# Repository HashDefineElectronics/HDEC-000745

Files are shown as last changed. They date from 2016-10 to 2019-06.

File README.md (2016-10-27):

# HDEC-000745
Robot and image processing developement platform

## Project page
https://www.hashdefineelectronics.com/micro-robot-development-platform-hdec-000745/

## Video
3D printing micro robot chassis (time lapse)

#3 time lapse 3D printing micro robot chassis (https://youtu.be/097JlulddWc)

# 1) Initial project setup
When you first clone the project you will need to use the --recursive parameter to clone any of the git submodules used by the project.

`git clone --recursive https://github.com/HashDefineElectronics/HDEC-000745.git`

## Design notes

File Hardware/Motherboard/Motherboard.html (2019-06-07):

# BOM Rev

Date

Company

Comment 1

Comment 2

Comment 3

Comment 4

Total Parts

# 18 (Unique 12)

Ref

Qty

Value

Footprint

C_Value

Description

Manufacture

Supplier

Supplier No.

[C] -

C1 C2

2

MC0402N300J500CT

Capacitors:CAP_0402

30pF 50V 5%

30pF 50V 0402 -55C to 125C COG/NP0 5%

KEMET

Farnell

1758954

C3 C4 C5

3

C0402C104K4RACAUTO

Capacitors:CAP_0402

100nF 16V 10%

100nF 16V 0603 -55C to 125C X7R 10% Automotive

KEMET

Farnell

2070374

C6

1

C0805C106K8PACTU

Capacitors:CAP_0805

10uF 10V 10%

10uF 10V 0805 X5R 10%

KEMET

Farnell

1463362

[D] -

D1

1

KP-1608SURCK

Diodes:LED_1.6mmx0.8mm

Red

Red 0.8mm 1.6mm SMD LED

KINGBRIGHT

Farnell

2290329

[J] -

J1

1

DEBUG_ARM_SW

Connectors:SHF-105-01-L-D-TH

ARM 10-Pin Serial Wire Connector (1.27mm)

SAMTEC

Farnell

2308450

[R] -

R1

1

MCMR04X1004FTL

Resistors:RES_0402

1M 62.5mW 1%

1M 0402 1% 62.5mW

MULTICOMP

Farnell

2072521

R2

1

ERJ2RKF2003X

Resistors:RES_0402

200K 0.1W 1% 75V

200K 0402 1% 0.1W 75V

PANASONIC ELECTRONIC COMPONENTS

Farnell

2059185

R3

1

ERJ2RKF1001X

Resistors:RES_0402

1K 0.1W 1%

1K 0402 1% 0.1W

PANASONIC ELECTRONIC COMPONENTS

Farnell

2302638

R4

1

CRCW0402100KFKEDHP

Resistors:RES_0402

100K 0.125W 1% 50V

100K 0402 1% 0.125W 50V

VISHAY DRALORIC

Farnell

1738877

[T] -

T1 T2 T3 T4

4

TEST_PAD

HDE_Miscellaneous:TEST_PAD_0.5mm_Hole

0.5mm Test pad

[U] -

U1

1

S9KEAZ64ACLH

IC:LQFP_64

ARM Cortex M0+ 64KB Flash 3.3V/5V LQFP-64

Freescale

Mouser

841-S9KEAZ64ACLH

[X] -

X1

1

ABM7-12.000MHZ-D2Y-T

HDE_Crystals:ABM7

12MHZ 18PF

CRYSTAL 12MHZ 18PF - 40°C to + 60°C

ABRACON

Farnell

2101331

# BOM made with KICAD_BOM_WIZARD (https://github.com/HashDefineElectronics/KiCad_BOM_Wizard) (Generated Wed 21 Jun 2017 15:26:22 BST)

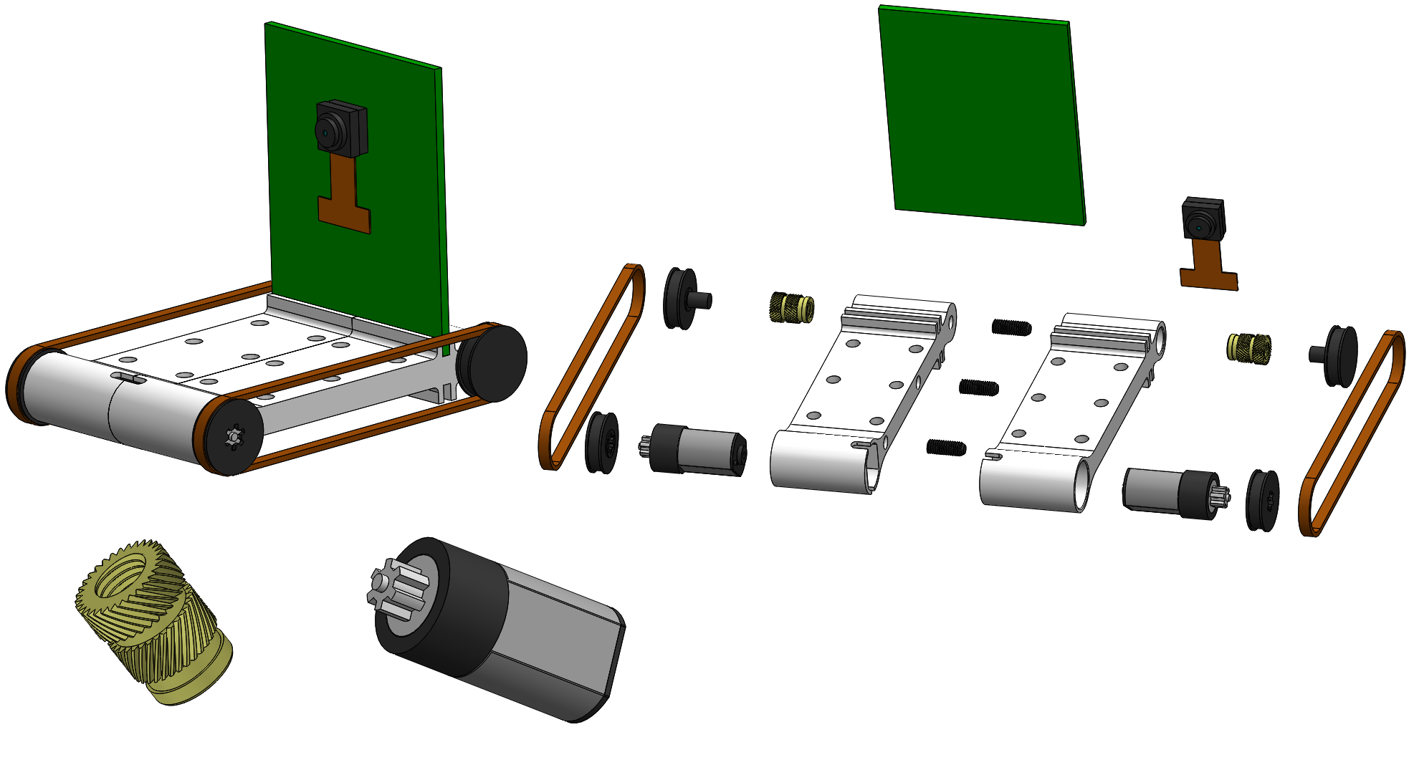
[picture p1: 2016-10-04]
Mechanical/Prototype render.png

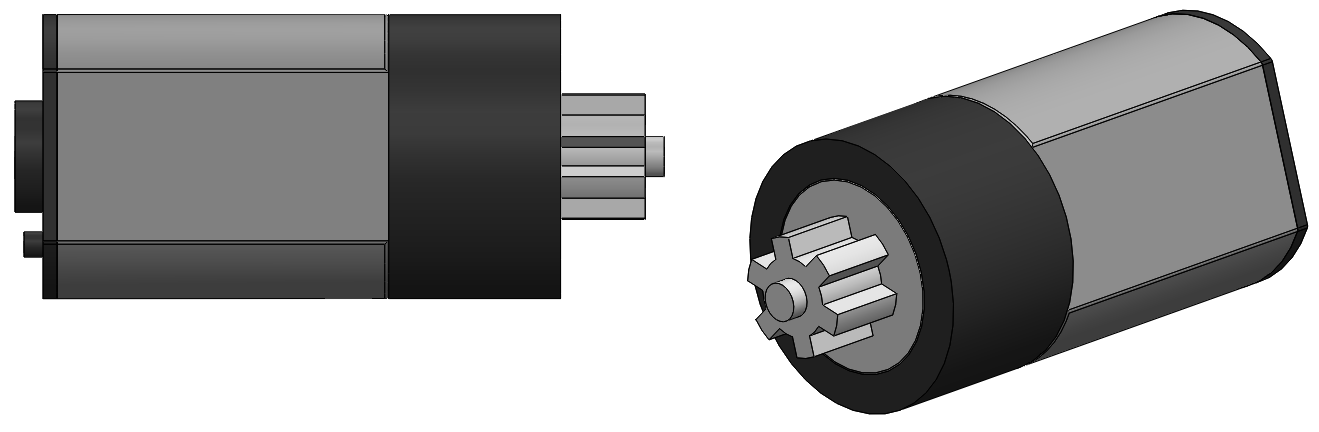
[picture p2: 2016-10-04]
Mechanical/Motor Render.png

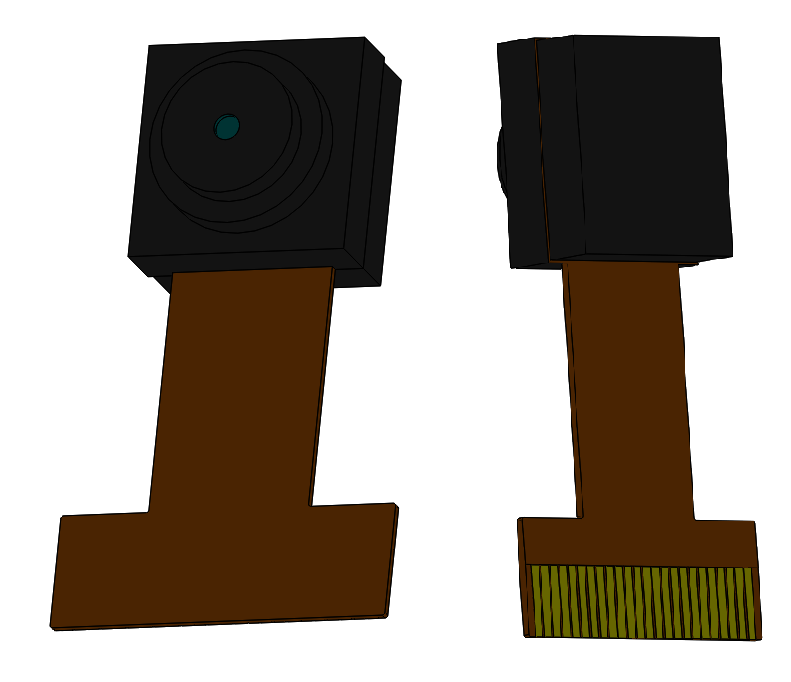
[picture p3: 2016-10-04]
Mechanical/Camera Render.png

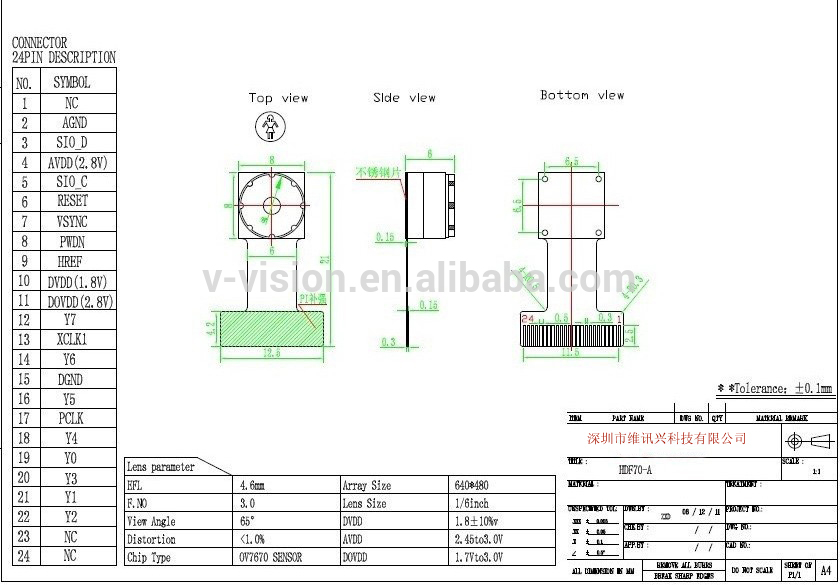
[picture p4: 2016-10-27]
Datasheet/HTB10HZ5FVXXXXb0XFXXq6xXFXXXZ.jpg

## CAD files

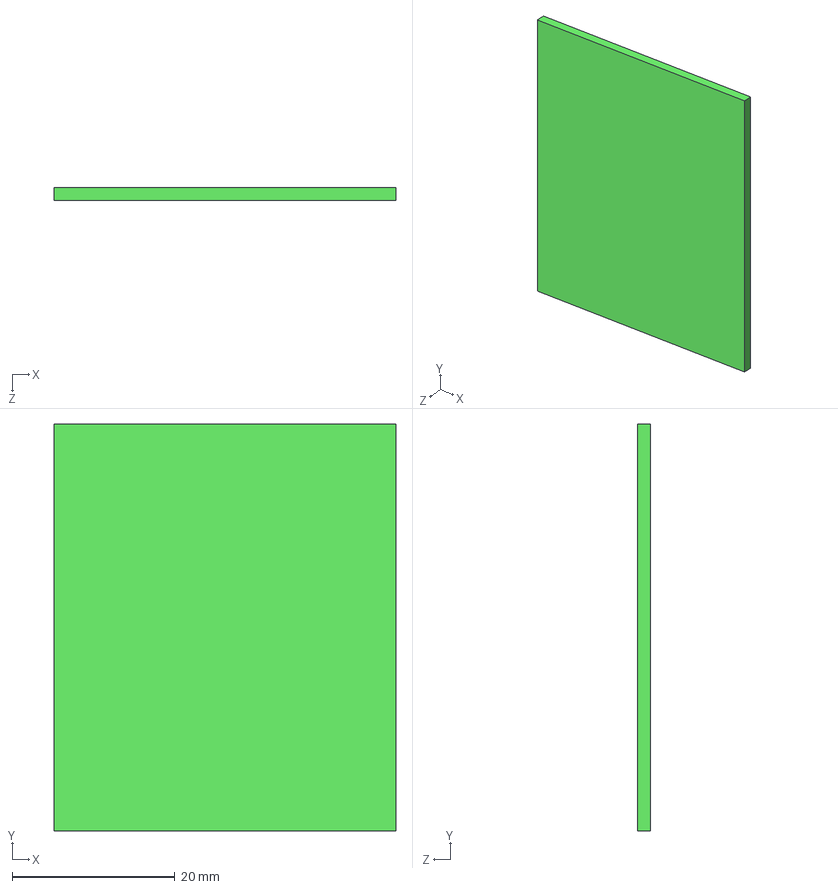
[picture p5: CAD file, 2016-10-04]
Mechanical/pcb.STEP
42.0 x 50.0 x 1.60 mm

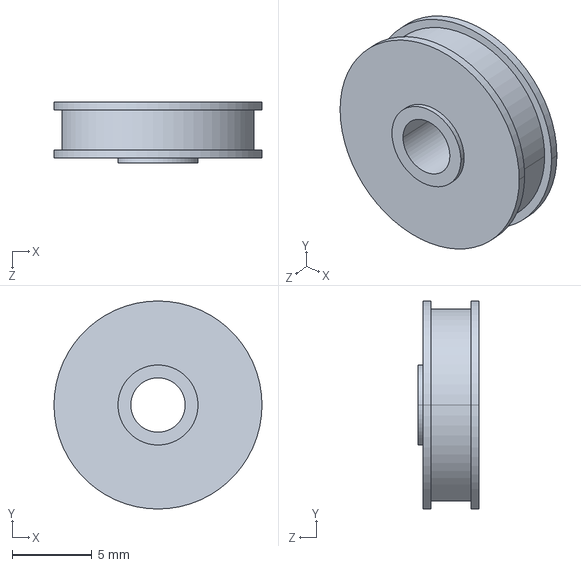
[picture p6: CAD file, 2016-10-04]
Mechanical/BackWheel.STEP
13.0 x 13.0 x 3.80 mm

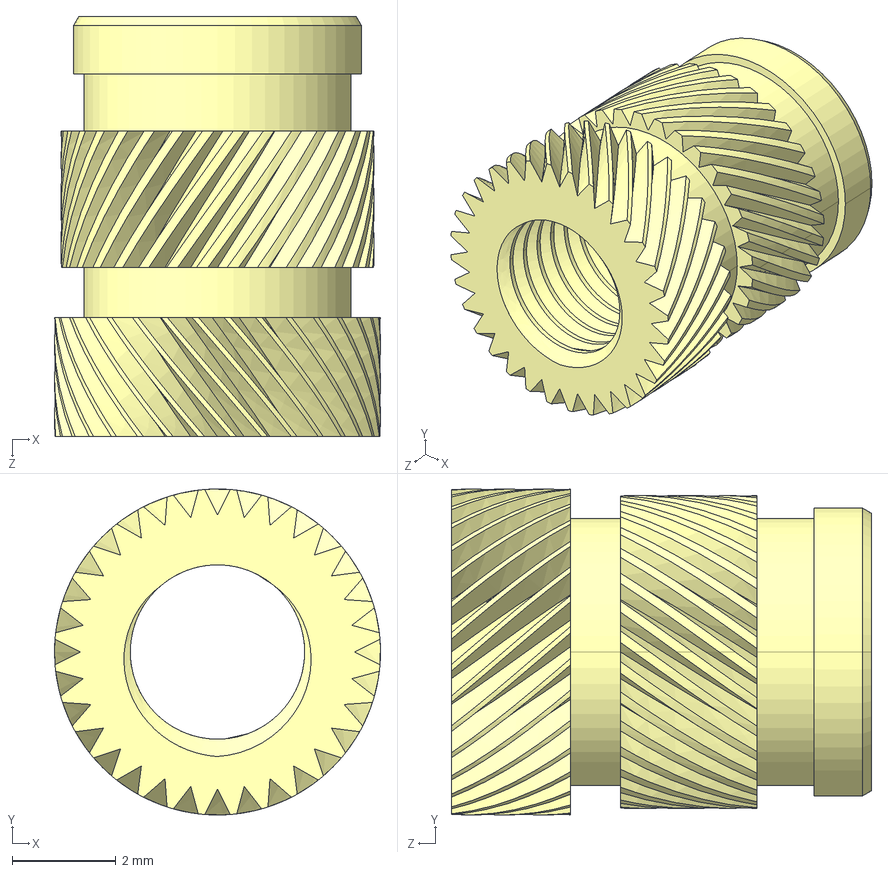
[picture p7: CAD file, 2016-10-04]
Mechanical/M3 Insert.STEP
6.28 x 6.28 x 8.10 mm

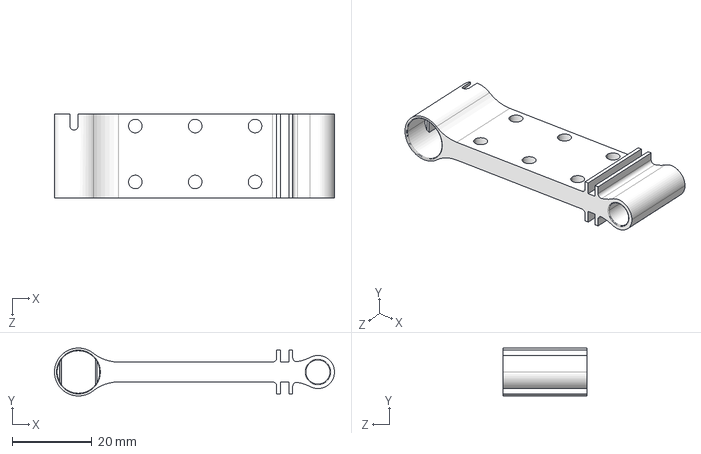
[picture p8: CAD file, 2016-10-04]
Mechanical/chassis.STEP
70.1 x 12.0 x 21.0 mm

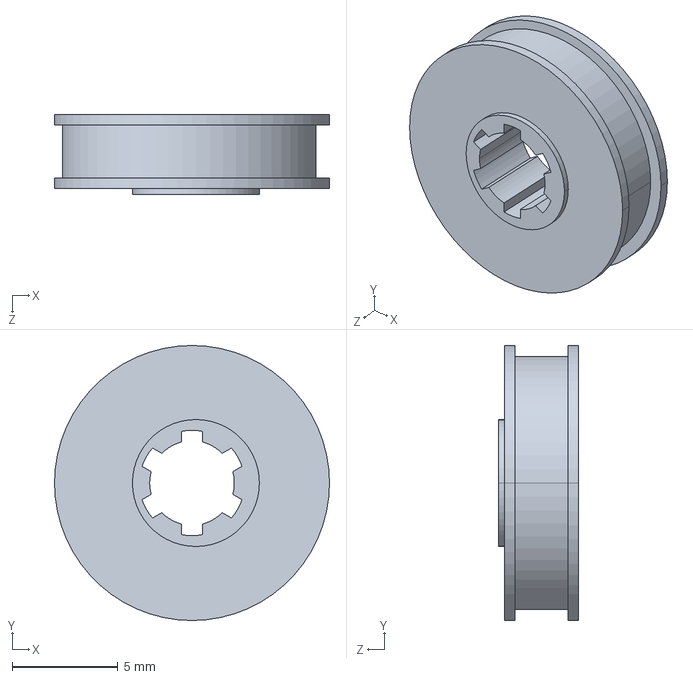
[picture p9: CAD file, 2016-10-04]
Mechanical/DriveWheel.STEP
13.0 x 13.0 x 3.80 mm

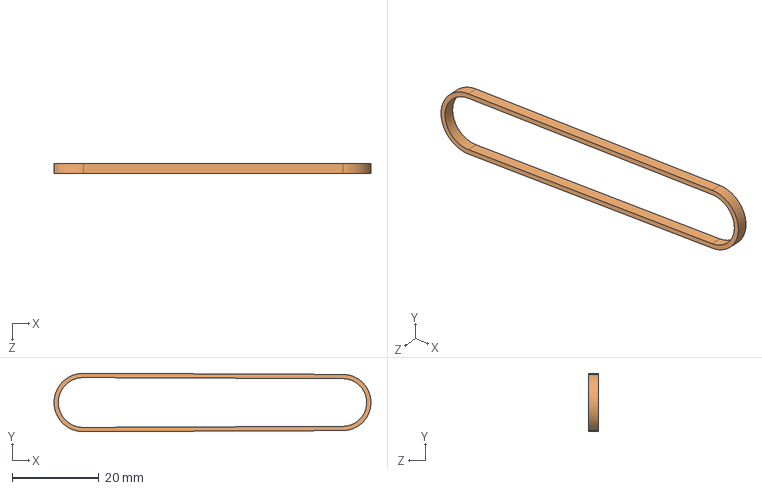
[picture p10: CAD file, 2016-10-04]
Mechanical/Belt1-9.STEP
73.2 x 13.5 x 2.40 mm

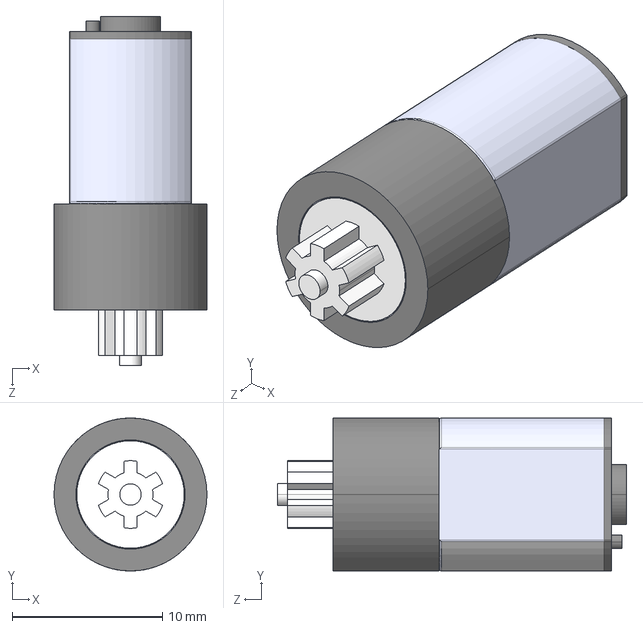
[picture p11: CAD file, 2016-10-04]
Mechanical/Motor.STEP
10.2 x 10.2 x 23.2 mm

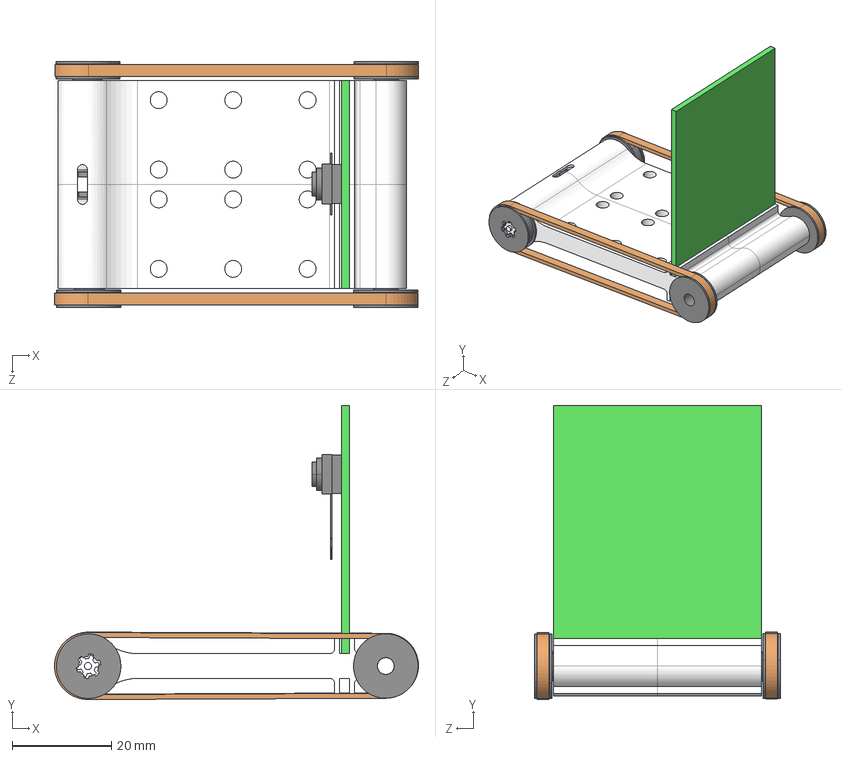
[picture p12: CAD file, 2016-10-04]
Mechanical/Robot CHassis.STEP
73.3 x 59.2 x 49.6 mm
chassis x 2
Motor x 2
M3 Grub screw x 3
M3 Insert x 2
DriveWheel x 2
pcb
Camera
BackWheel x 2
Belt1-9 x 2

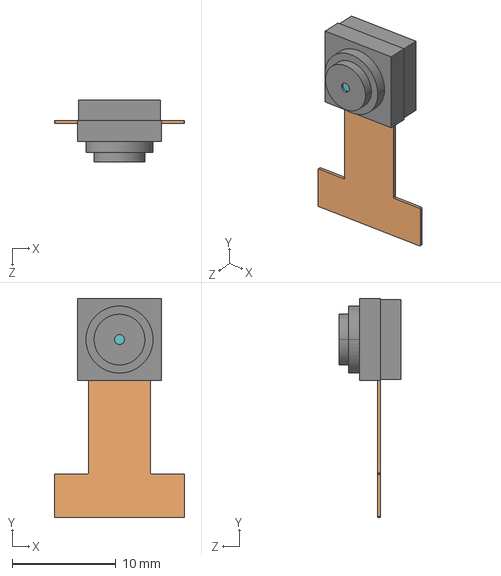
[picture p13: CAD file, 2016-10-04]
Mechanical/Camera.STEP
12.6 x 21.1 x 6.00 mm

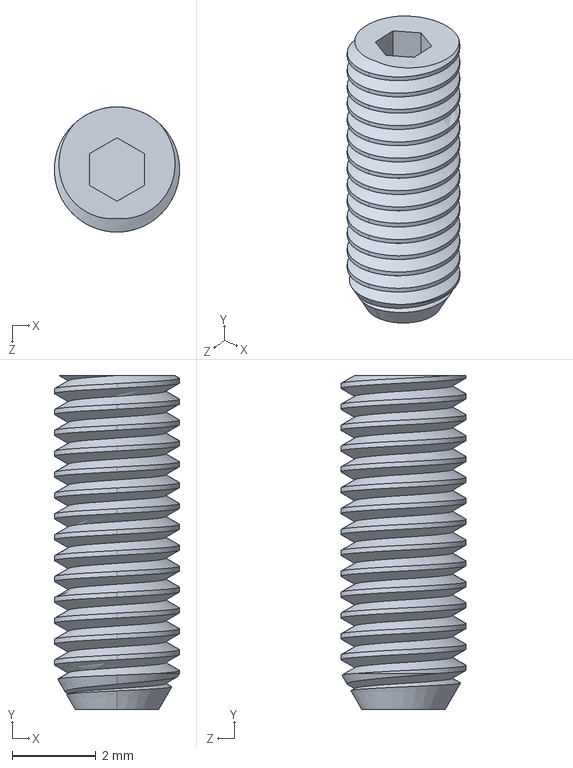
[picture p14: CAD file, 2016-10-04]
Mechanical/M3 Grub screw.STEP
3.00 x 8.00 x 3.00 mm

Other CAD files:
Mechanical/Belt1-7.STEP
Mechanical/Belt2-8.STEP
Mechanical/BackWheel.SLDPRT
Mechanical/BackWheel.STL
Mechanical/Belt1-7.sldprt
Mechanical/Belt1-9.sldprt
Mechanical/Belt2-8.sldprt
Mechanical/Camera.SLDPRT
Mechanical/DriveWheel.SLDPRT
Mechanical/DriveWheel.STL
Mechanical/M3 Grub screw.DWG
Mechanical/M3 Grub screw.SLDPRT
Mechanical/M3 Insert.SLDPRT
Mechanical/Motor.SLDPRT
Mechanical/Robot CHassis.SLDASM
Mechanical/chassis.SLDPRT
Mechanical/chassis.STL
Mechanical/pcb.SLDPRT

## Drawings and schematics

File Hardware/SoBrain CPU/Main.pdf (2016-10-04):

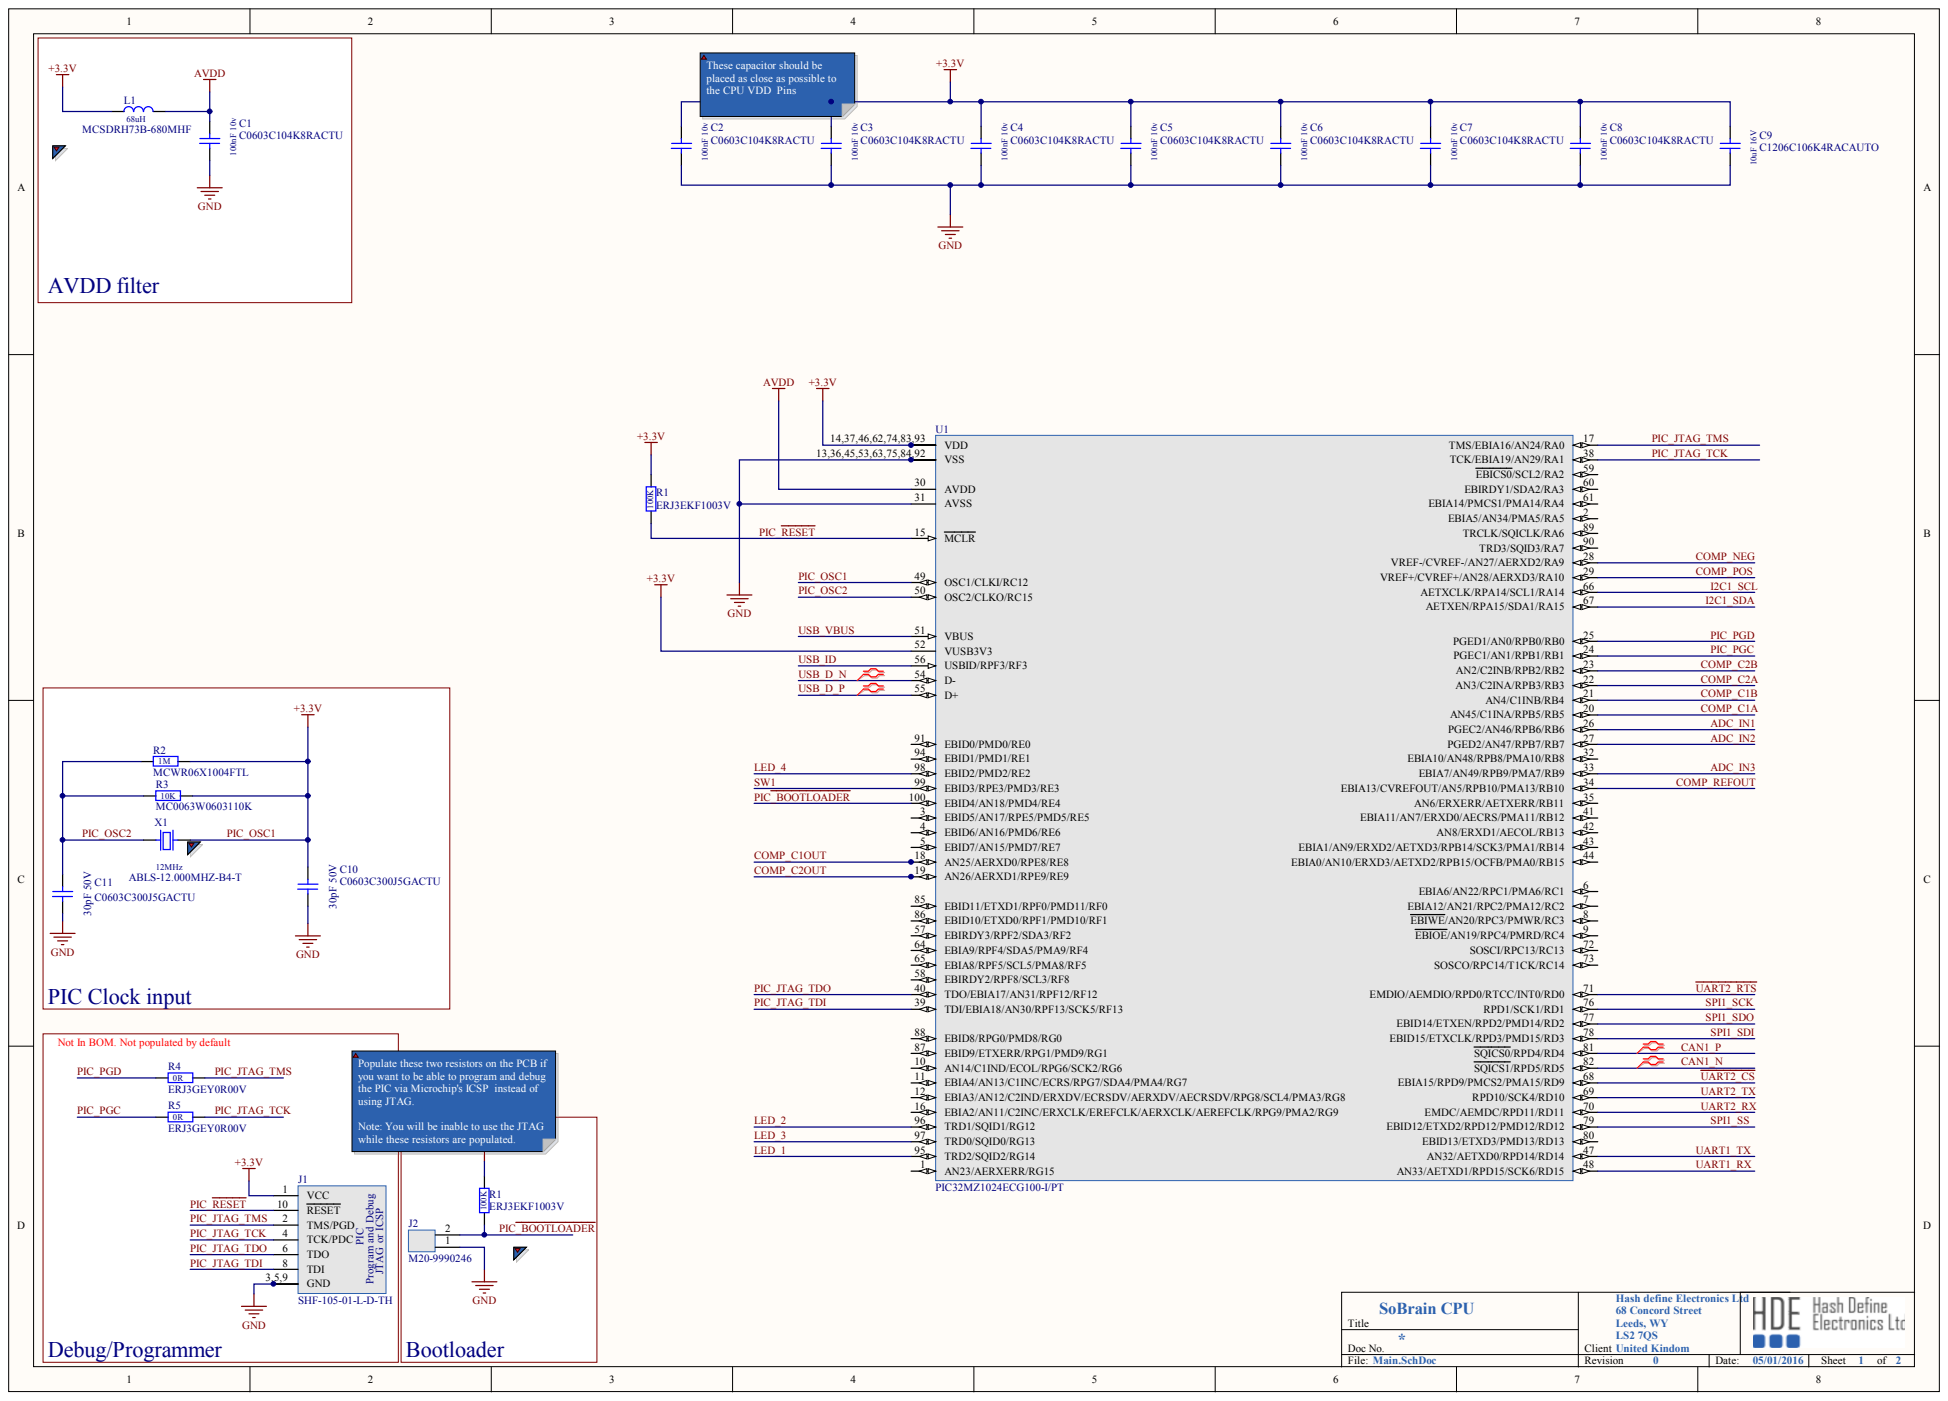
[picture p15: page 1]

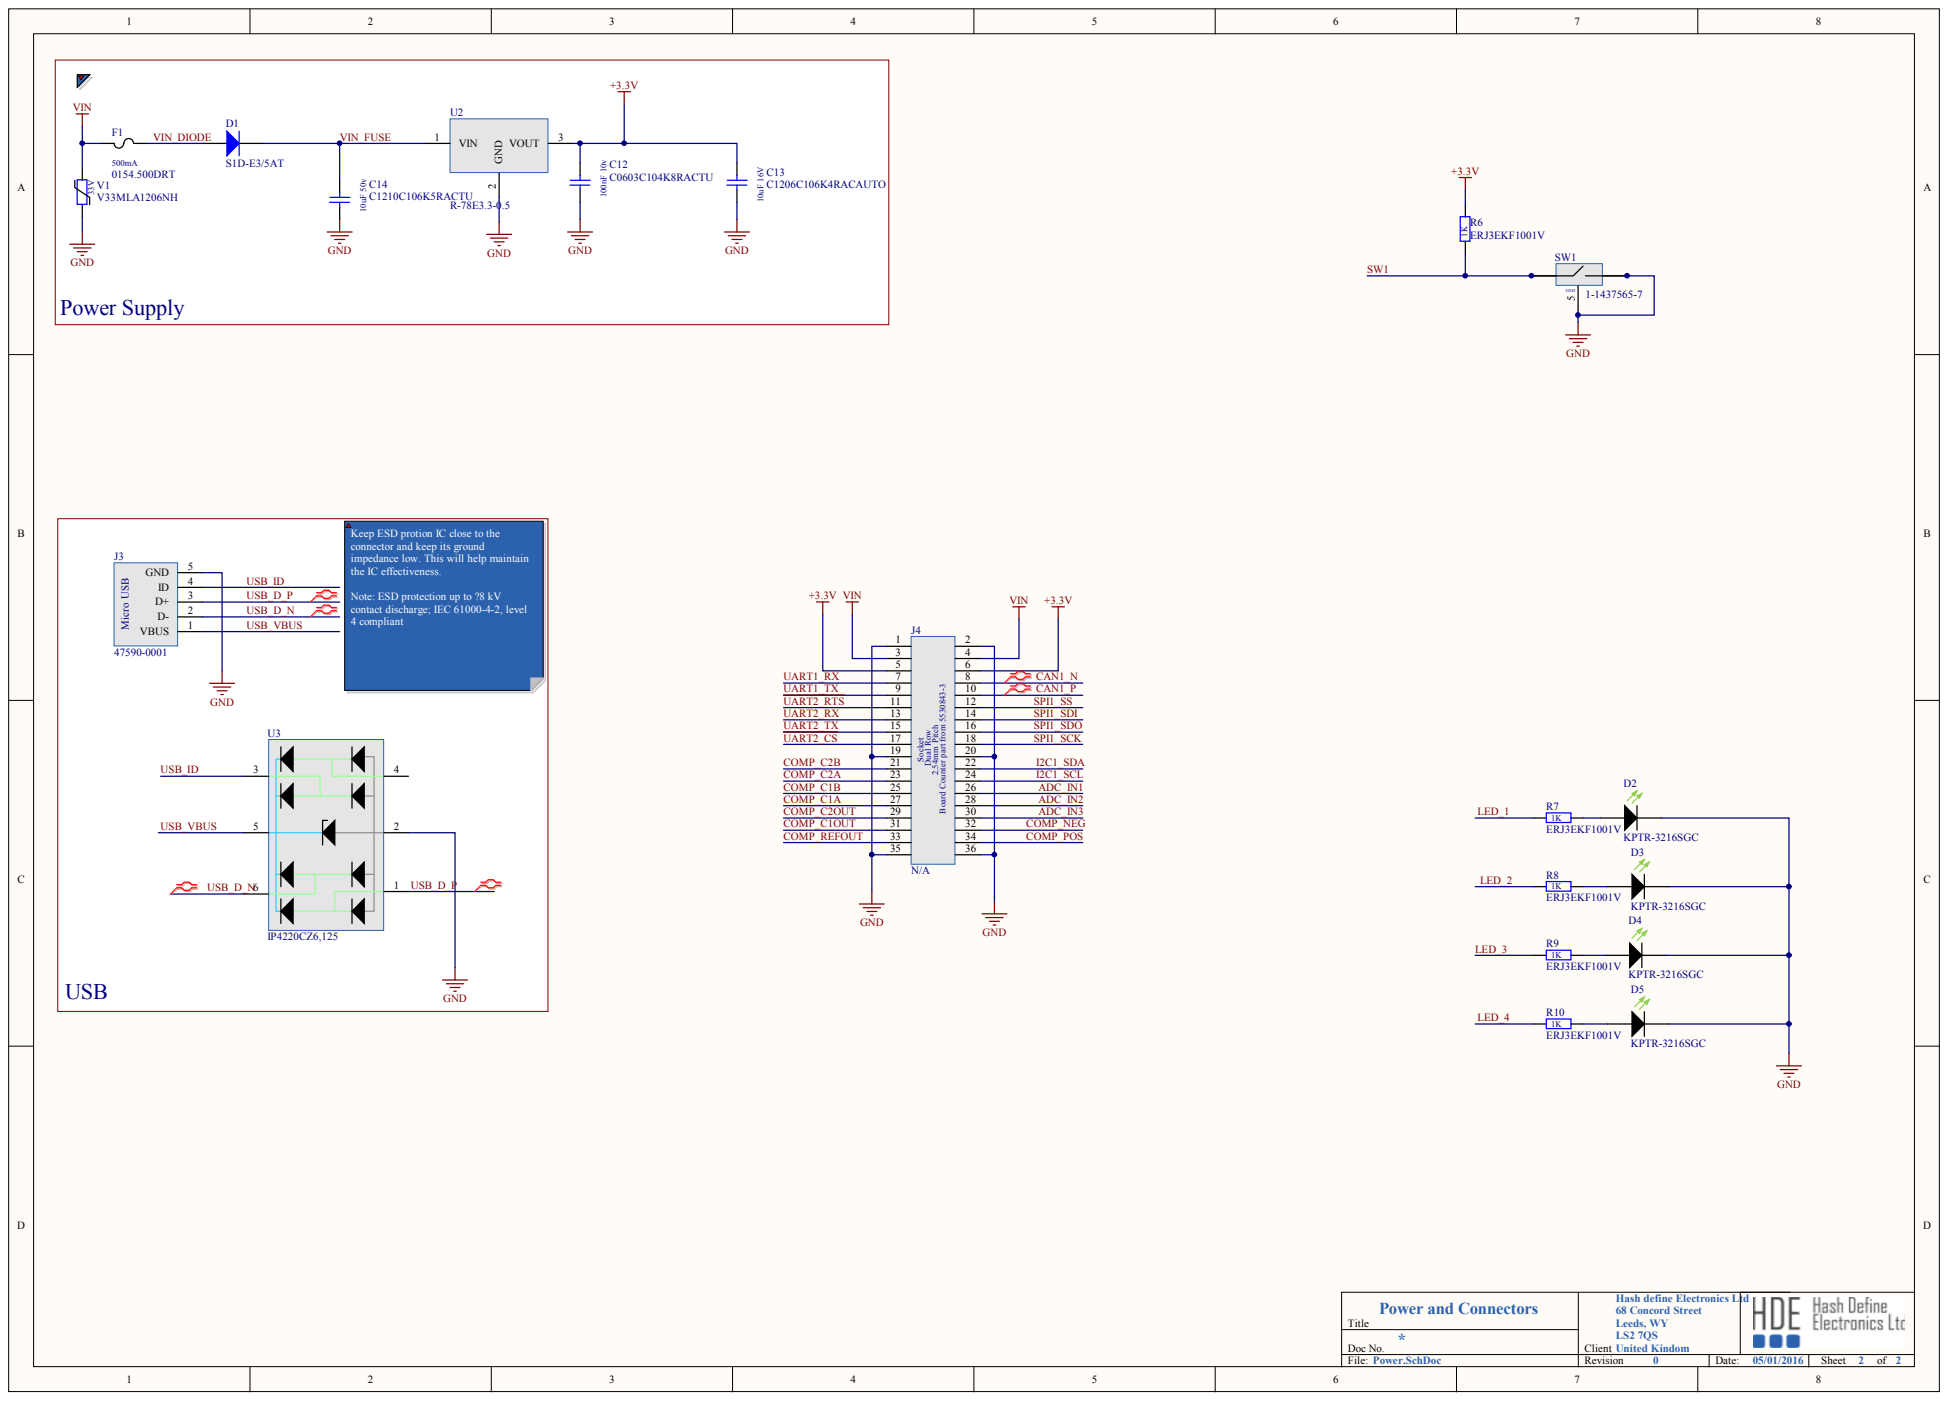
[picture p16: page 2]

1 D-2 D+ 3 ID 4 GND 5

USB_D_P
USB_D_N
USB_VBUS

7 9 1 1 1 3 1 5 1 7 1 9 | 8 1 0 1 2 1 4 1 6 1 8 2 0

Board Counter part from 5530843-3

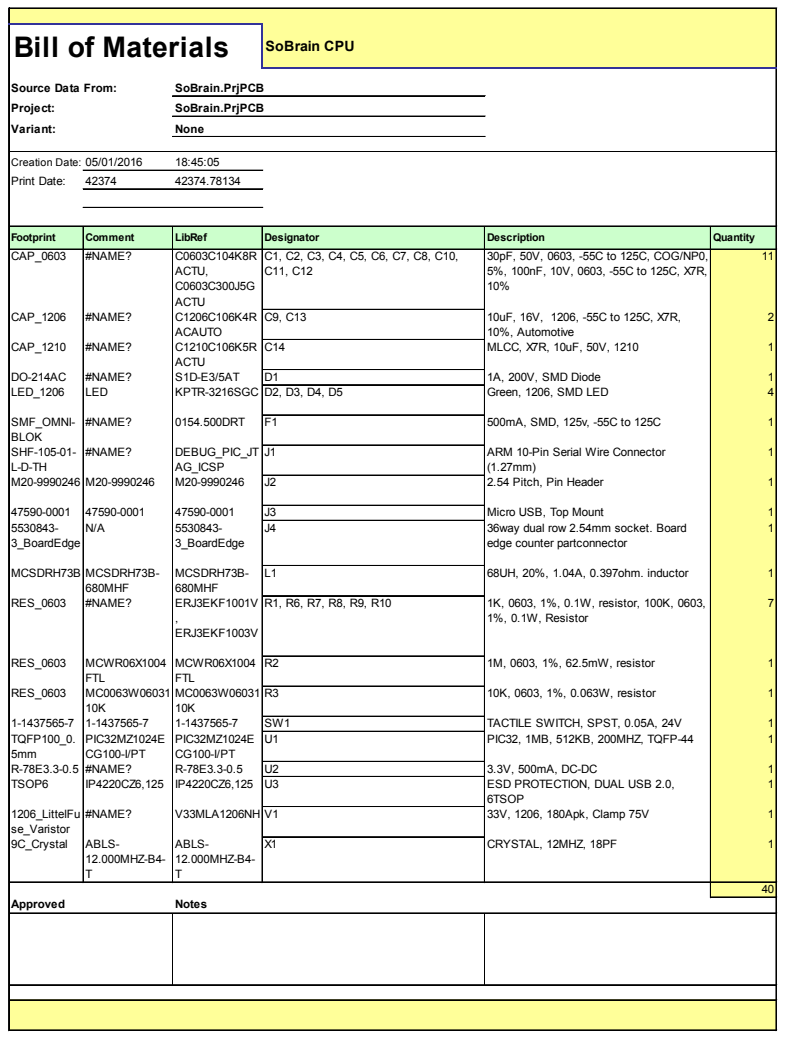
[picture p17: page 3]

Footprint | Comment | LibRef | Designator | Description | Quantity

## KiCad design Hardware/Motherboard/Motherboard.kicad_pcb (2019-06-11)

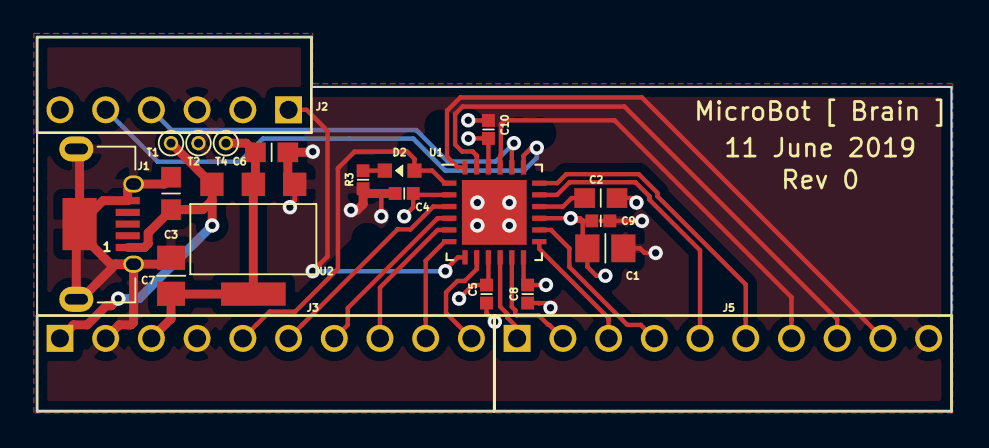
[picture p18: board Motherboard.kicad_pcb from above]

Board: 4 copper layers, 50.8 x 20.8 mm, 21 parts (0 on the bottom side), 23 nets.

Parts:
C1, C7: C0805C106K8PACTU; CAP_0805
C2: GRM188R71E105KA12D; CAP_0603
C3, C6: C0603C104K4RACTU; CAP_0603
C4, C5, C8, C9, C10: C0402C104K4RACAUTO; CAP_0402
D2: KP-1608SURCK; LED_1.6mmx0.8mm
J1: 47590-0001
J2: 61300611021; 6pin_1row_2.54mm_right_angle
J3, J5: 61301011021; 10pin_1row_2.54mm_right_angle
R3: ERJ2RKF1001X; RES_0402
T1, T2, T4: TEST_PAD; TEST_PAD_0.5mm_Hole
U1: EFM32ZG108F32-QFN24; QFN-24_EP_5x5_Pitch0.65mm
U2: LD1117S33CTR; SOT223

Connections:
+3V3: C1.1, C4.1, C5.1, C6.1, C7.1, C8.1, C9.1, C10.1, J2.2, J3.3, T4.1, U1.2, U1.9, U1.12, U1.15, U1.22, U2.2, U2.4
+5V: C3.1, J1.1, J3.1, T1.1, U2.3
/Micro_P1_LED1: D2.1, J3.5, U1.1
/Micro_P2: J3.6, U1.3
/Micro_P3: J3.7, U1.4
/Micro_P4: J3.8, U1.5
/Micro_P5: J3.9, U1.6
/Micro_P6: J3.10, U1.8
/Micro_P7: J5.1, U1.10
/Micro_P8: J5.2, U1.11
/Micro_P9: J5.3, U1.13
/Micro_P10: J5.4, U1.14
/Micro_P11: J5.5, U1.17
/Micro_P12: J5.6, U1.18
/Micro_P13: J5.7, U1.21
/Micro_P14: J5.8, U1.23
/Micro_P15: J5.9, U1.24
/Micro_SWCLK: J2.5, U1.19
/Micro_SWDIO: J2.4, U1.20
/Micro_~RESET~: J2.1, U1.7
GND: C1.2, C2.2, C3.2, C4.2, C5.2, C6.2, C7.2, C8.2, C9.2, C10.2, J1.5, J1.6, J2.3, J3.2, J3.4, J5.10, R3.2, T2.1, U1.25, U2.1
unnamed: C2.1, U1.16
unnamed: D2.2, R3.1

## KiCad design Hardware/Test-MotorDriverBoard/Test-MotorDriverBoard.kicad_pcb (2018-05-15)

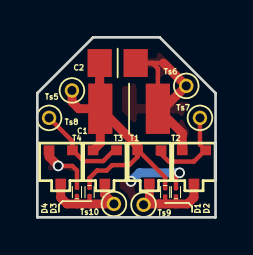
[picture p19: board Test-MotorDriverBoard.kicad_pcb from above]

Board: 2 copper layers, 9.9 x 10.0 mm, 16 parts (0 on the bottom side), 6 nets.

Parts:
C1: C1210C106K5RACTU; CAP_1210
C2: MC0805B104K500CT; CAP_0805
D1, D2, D3, D4: PMEG1201AESF; SOD962-2
T1, T3: NDS332P; SOT323
T2, T4: PMF370XN,115; SOT323
Ts5, Ts6, Ts7, Ts8, Ts9, Ts10: TEST_PAD; TEST_PAD_0.5mm_Hole

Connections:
+3V3: C1.1, C2.1, D1.1, D3.1, T1.2, T3.2, Ts5.1
/Input_1: T1.1, T2.1, Ts7.1
/Input_2: T3.1, T4.1, Ts8.1
/Motor_A: D1.2, D2.1, T1.3, T2.3, Ts9.1
/Motor_B: D3.2, D4.1, T3.3, T4.3, Ts10.1
GND: C1.2, C2.2, D2.2, D4.2, T2.2, T4.2, Ts6.1

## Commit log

2016-10-04 - added the KiCad Project with the HDE_PUB_LIB - added the mechanical files - added the original altimun design files
    [BackWheel.SLDPRT, BackWheel.STEP, BackWheel.STL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]
2016-10-04 updated the readme file to include the project page and the current video
2016-10-27 - added camera module datasheet - added stm32f429 datasheet - update the HDE_PUB_LIB submodule and Hardware/Motherboard project
    [Motherboard.sch]
2017-09-27 minor commit
    [Controller.sch, Motherboard.sch]
2017-09-28 added mosfet library to the project and created the test motor driver board PCB
    [Test-MotorDriverBoard.kicad_pcb, Test-MotorDriverBoard.sch]
2017-09-28 created the H-bridge shematic and PCB layout
    [Test-MotorDriverBoard.kicad_pcb, Test-MotorDriverBoard.sch]
2017-10-02 updated the library portion of the project
    [Test-MotorDriverBoard.kicad_pcb]
2017-10-02 upated kicad library
2017-10-02 Minor Components changes
    [Test-MotorDriverBoard.kicad_pcb, Test-MotorDriverBoard.sch]
2017-10-03 updated KiCad library version to the latest
2017-10-03 minor changes to the motor test board
    [Test-MotorDriverBoard.kicad_pcb, Test-MotorDriverBoard.sch]
2018-05-12 added the soft power switch. Will need to be verified.
    [Controller.sch, Motherboard.sch, Soft_power_sw.sch]
2018-05-15 Started work on adding the boost converter
    [Controller.sch, Motherboard.sch, Power.sch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]
2018-05-15 added the current changes from the test motor
    [Test-MotorDriverBoard.kicad_pcb, Test-MotorDriverBoard.sch]
2018-05-18 Partial Commit
    [Test-MotorDriverBoard.sch]
2019-06-07 Updated schematic and library
    [Controller.sch, Motherboard.sch, Power.sch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]
2019-06-07 Added the 20way connector and started to layout the main controller
    [Battery_Circuit.sch, Controller.sch, Motherboard.kicad_pcb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]
2019-06-11 I've layout the motherboard
    [Motherboard.kicad_pcb, Motherboard.sch]
